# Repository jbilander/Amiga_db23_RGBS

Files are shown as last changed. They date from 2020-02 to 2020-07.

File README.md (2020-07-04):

# Amiga_DB23_RGBS
A small PCB with RGBS out from the Amiga d-sub db23 connector. Made with KiCad 5.1.2-1

### Updated v2 PCB

On request I made an updated PCB with the capacitor pads removed, 2 mm hole pitch giving two more GND holes. A little rerouting as well to provide for easier soldering when using cables with shielded wire pairs (signal + ground return). This PCB is not tested yet!

<a href="images/Amiga_db23_RGBS_v2_pic1.jpg">
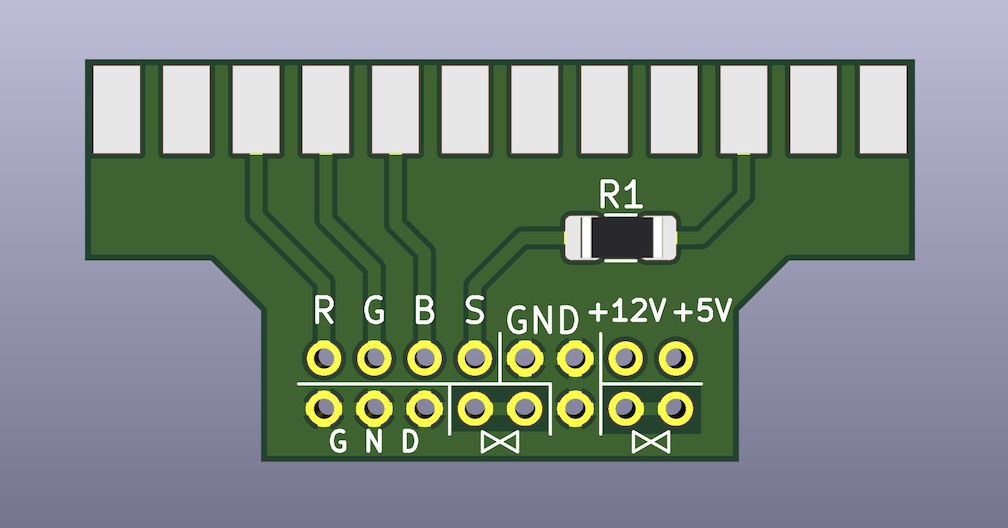
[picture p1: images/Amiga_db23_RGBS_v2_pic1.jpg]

</a>
<a href="images/Amiga_db23_RGBS_v2_pic2.jpg">
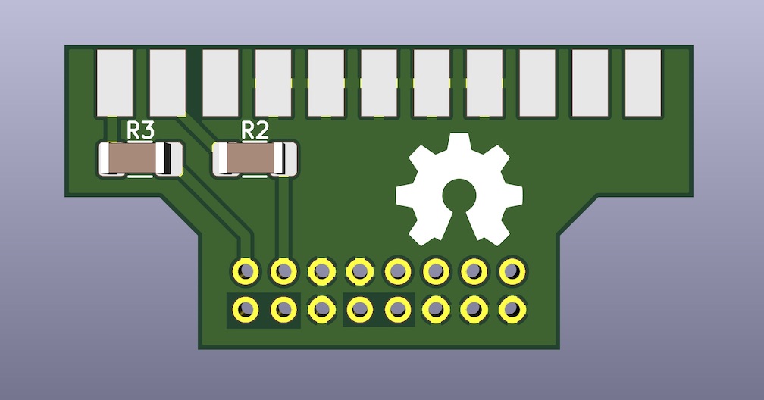
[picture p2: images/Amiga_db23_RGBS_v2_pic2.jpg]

</a>
<a href="images/Amiga_db23_RGBS_v2_pic3.jpg">
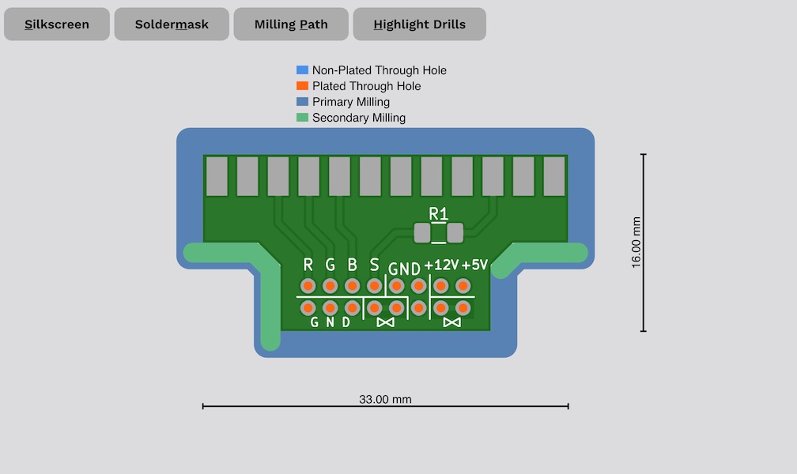
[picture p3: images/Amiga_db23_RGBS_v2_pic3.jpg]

</a>
<a href="images/Amiga_db23_RGBS_v2_pic4.jpg">
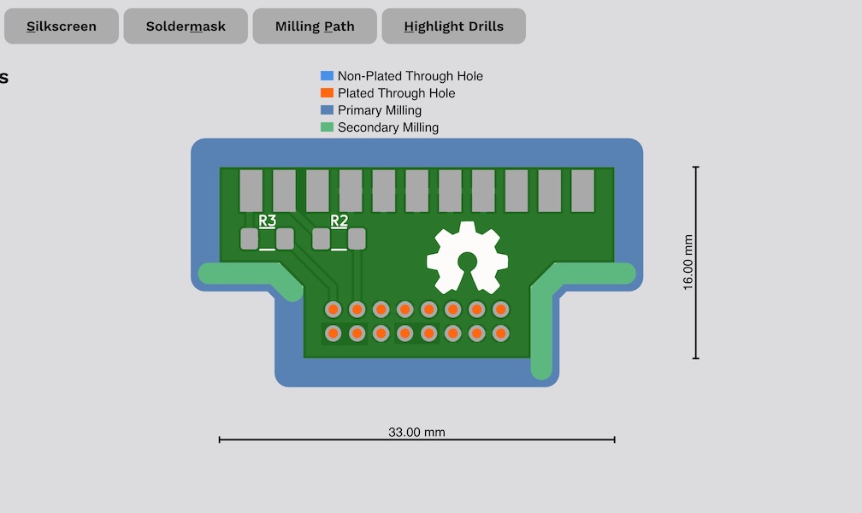
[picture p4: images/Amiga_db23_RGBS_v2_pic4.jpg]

</a>
<a href="images/Amiga_db23_RGBS_v2_pic5.jpg">
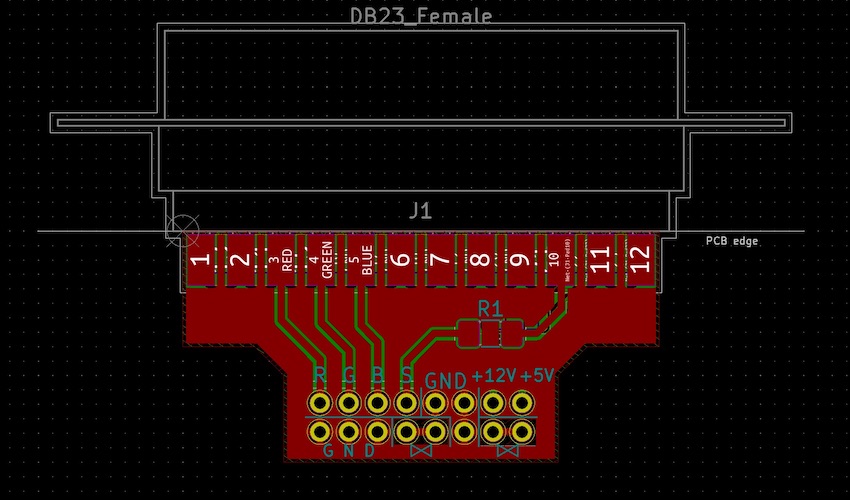
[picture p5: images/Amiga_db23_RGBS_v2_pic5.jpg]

</a>

***

Update: On some cables I got a lot of noise/interference in the signal and needed to connect the shielding on the plugs on each end `d-sub metal shield <-> SCART metal shield` to get rid of it.

***

<a href="images/Amiga_db23_RGBS_pic1.jpg">
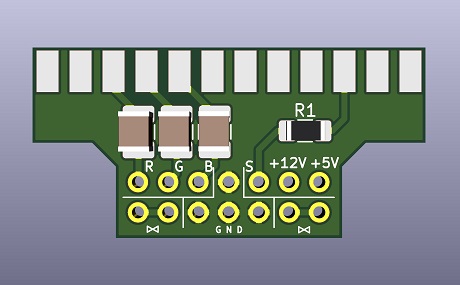
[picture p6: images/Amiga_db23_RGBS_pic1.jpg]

</a>
<a href="images/Amiga_db23_RGBS_pic2.jpg">
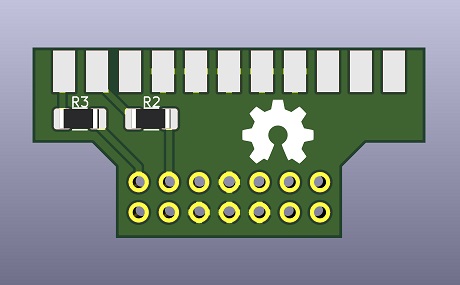
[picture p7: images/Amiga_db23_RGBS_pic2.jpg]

</a>
<a href="images/Amiga_db23_RGBS_pic3.jpg">
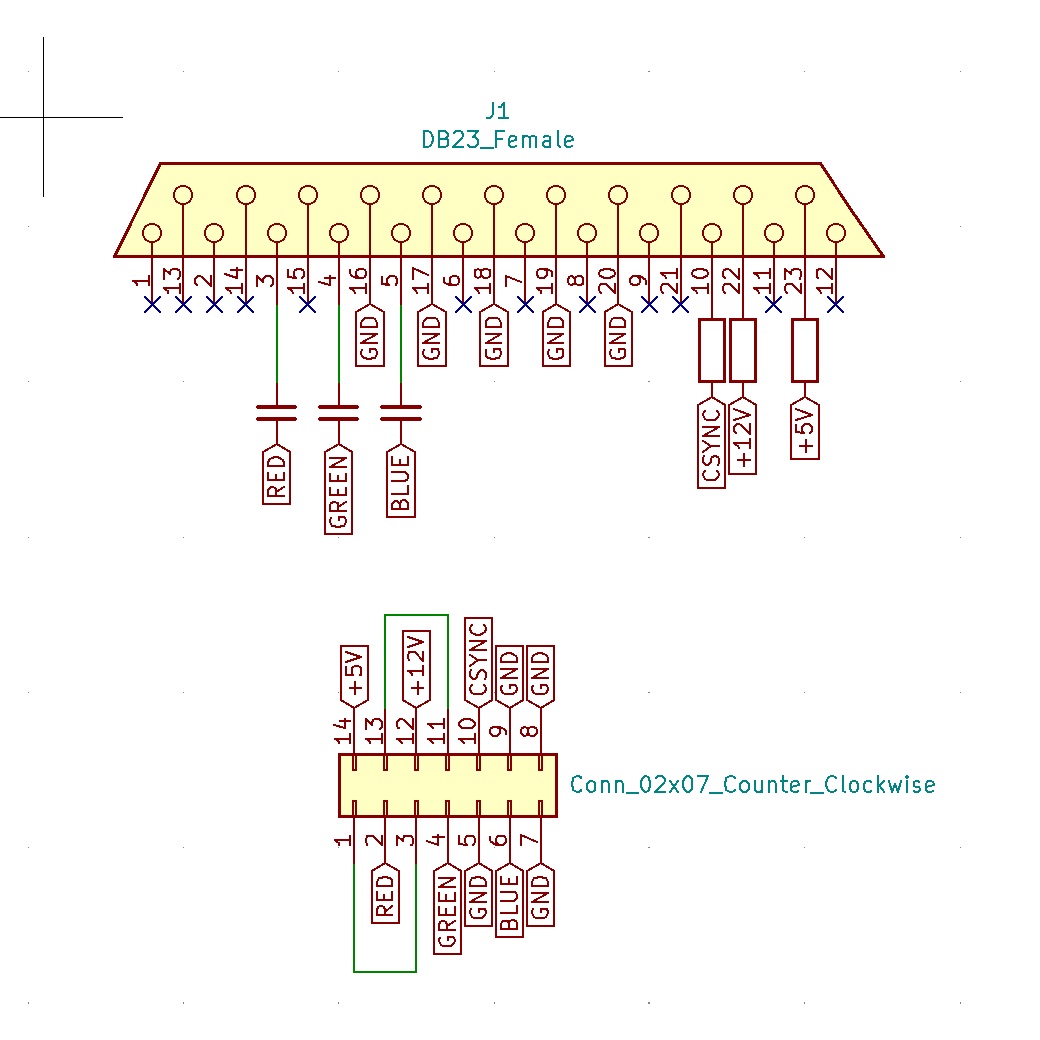
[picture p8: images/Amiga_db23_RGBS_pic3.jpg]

</a>
<a href="images/Amiga_db23_RGBS_pic4.jpg">
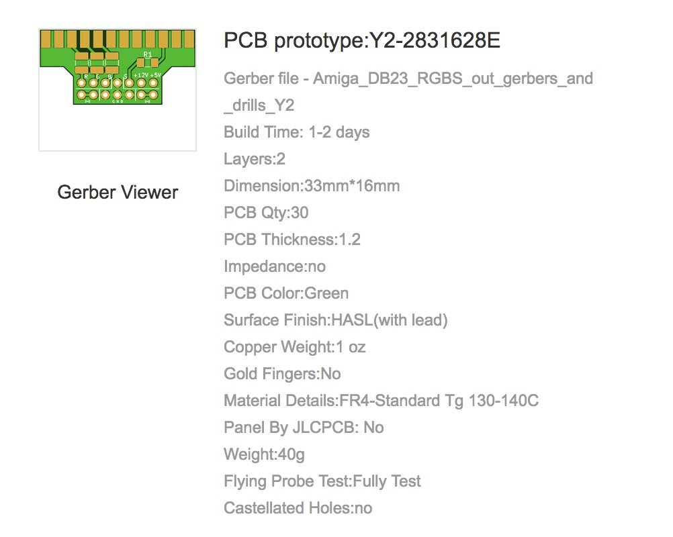
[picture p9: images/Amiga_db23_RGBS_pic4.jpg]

</a>

***

<a href="images/Amiga_db23_RGBS_pic5.jpg">
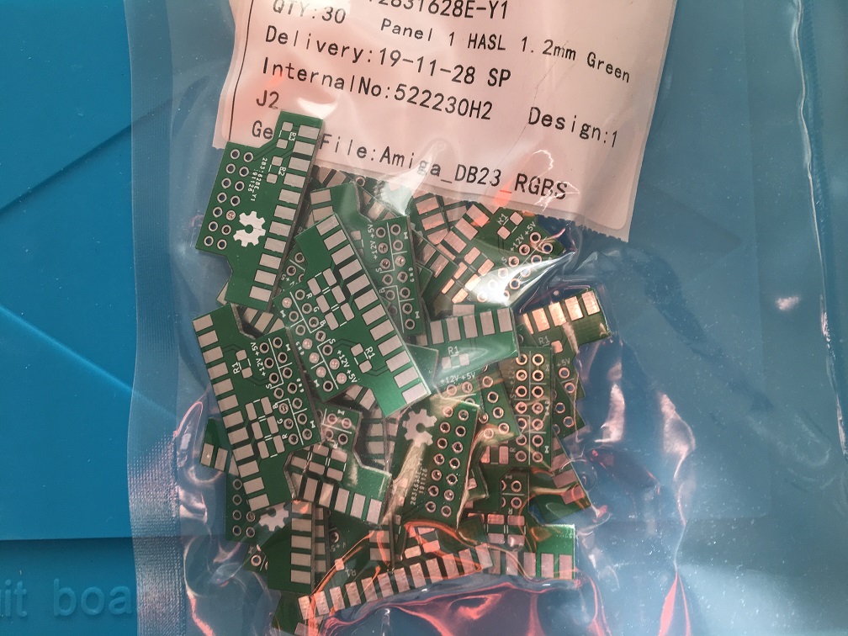
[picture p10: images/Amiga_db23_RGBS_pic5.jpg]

</a>
<a href="images/Amiga_db23_RGBS_pic6.jpg">
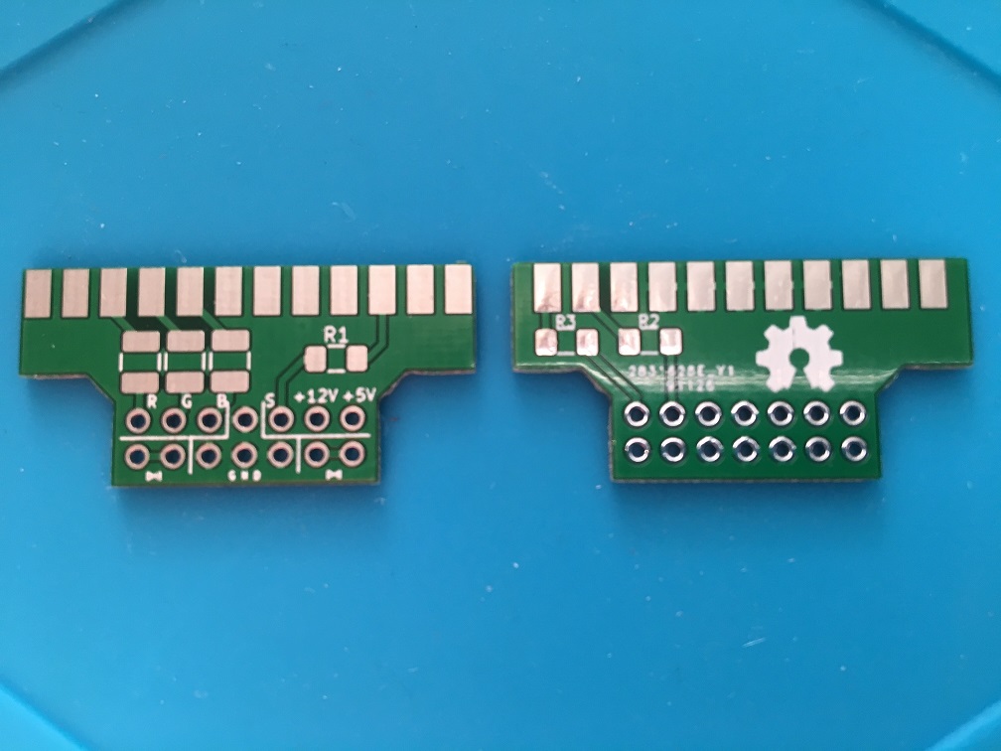
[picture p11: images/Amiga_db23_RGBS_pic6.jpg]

</a>
<a href="images/Amiga_db23_RGBS_pic7.jpg">
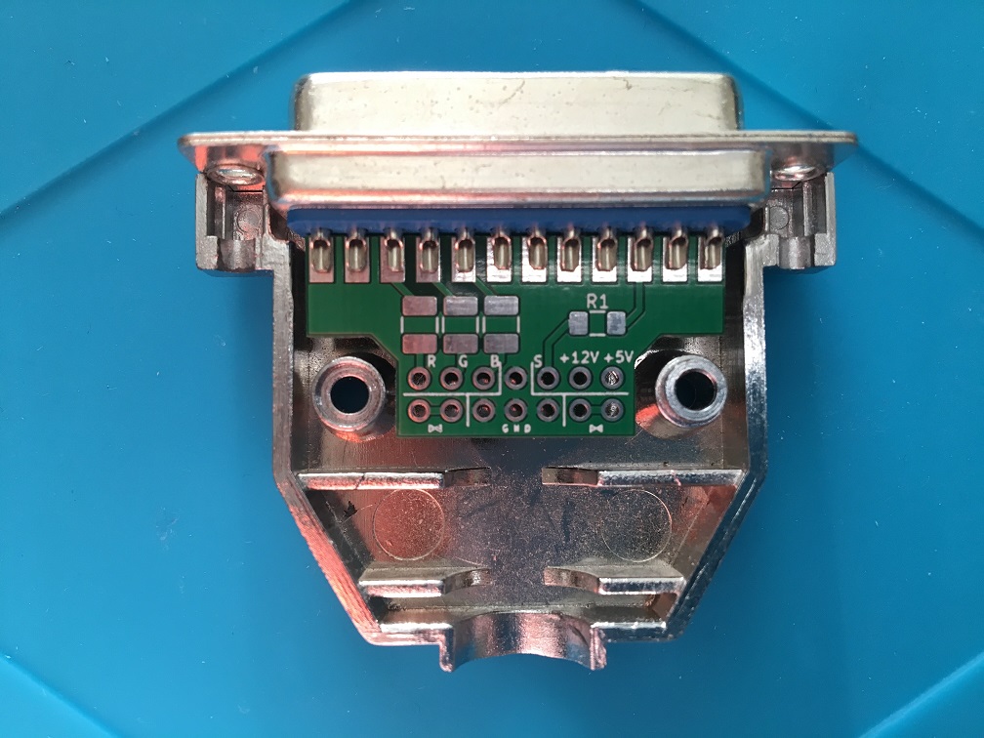
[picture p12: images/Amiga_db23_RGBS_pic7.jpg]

</a>

***

Let's solder this one. I used `220uF 16V size 1210` as coupling capacitors for the RGB pads. All resistors `size 1206`, I used the following values `R1: 330 Ohm, R2: 1K Ohm, R3: 75 Ohm`, following Stedy's guide here: The Ultimate SCART cable v1.1 http://www.ianstedman.co.uk/Amiga/amiga_hacks/Amiga_SCART/amiga_scart.html Not using pin 13 though as ground return but rather following this picture: https://ilesj.files.wordpress.com/2012/01/amiga_rgb-scart-diagram.png

<a href="images/Amiga_db23_RGBS_pic9.jpg">
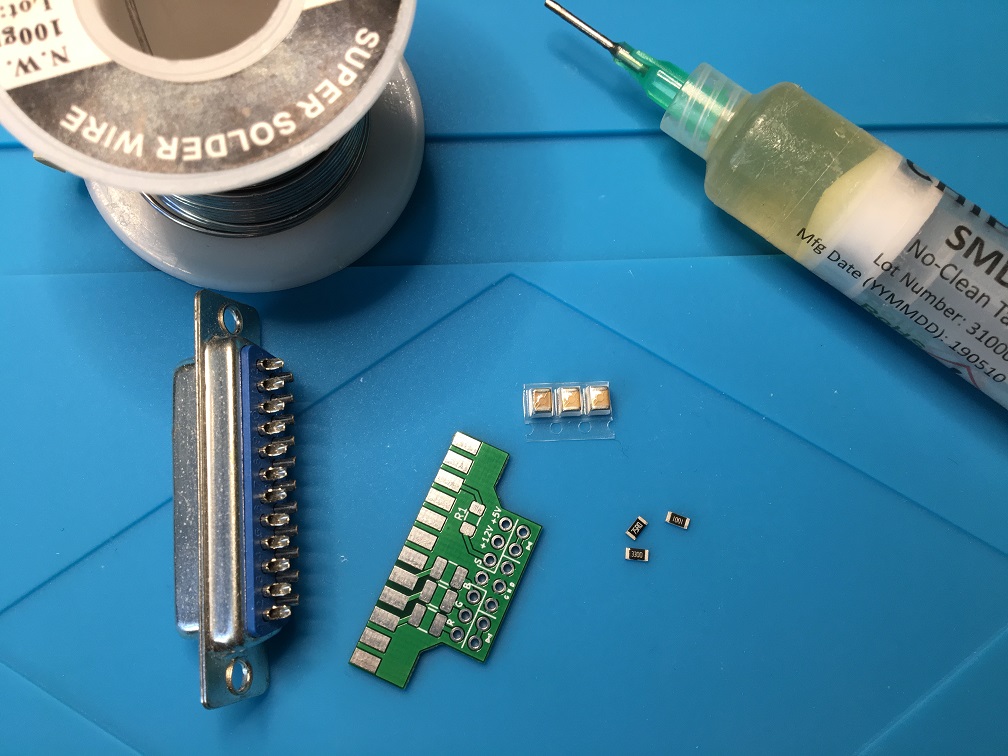
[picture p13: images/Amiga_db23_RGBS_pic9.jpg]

</a>
<a href="images/Amiga_db23_RGBS_pic10.jpg">
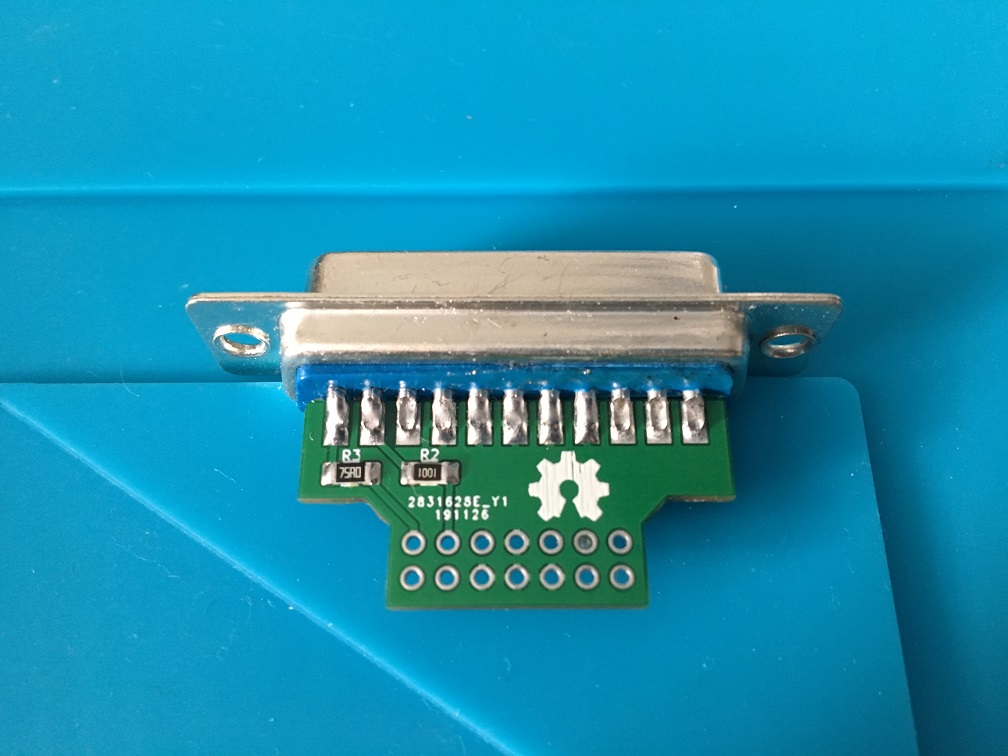
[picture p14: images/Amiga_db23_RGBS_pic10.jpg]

</a>
<a href="images/Amiga_db23_RGBS_pic11.jpg">
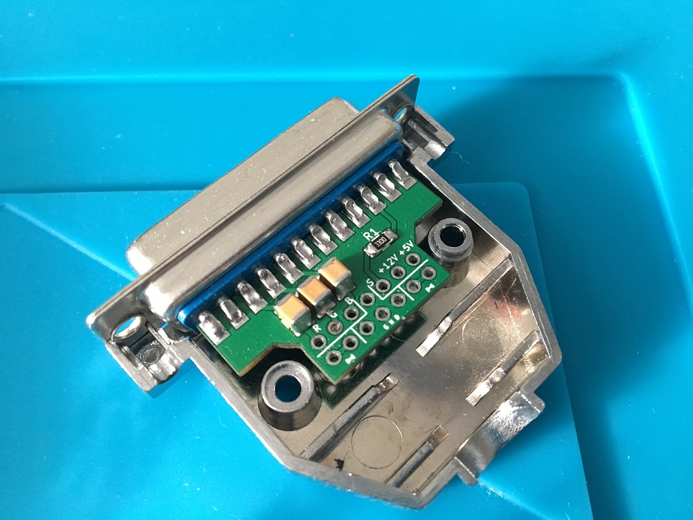
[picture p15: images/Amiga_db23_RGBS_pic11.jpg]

</a>

***
I used an old DVI<->Vga cable that I butchered cutting off the plugs on both ends. I also found an old composite rca cable yellow-red-white laying around. I used the red-white part for the Audio. When making a cable with a SCART plug it makes sense to run the Left/Right audio wires inside the cable since the connector has both RGB video and stereo audio pins as standard. You can run the audio wires separately should you want to.

<a href="images/Amiga_db23_RGBS_pic12.jpg">
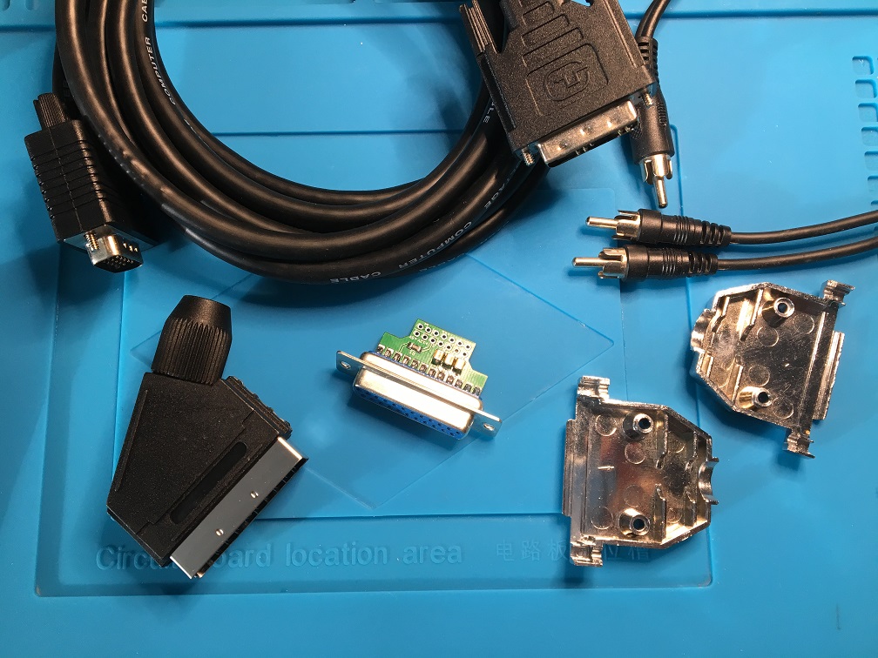
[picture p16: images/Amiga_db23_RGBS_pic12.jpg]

</a>
<a href="images/Amiga_db23_RGBS_pic13.jpg">
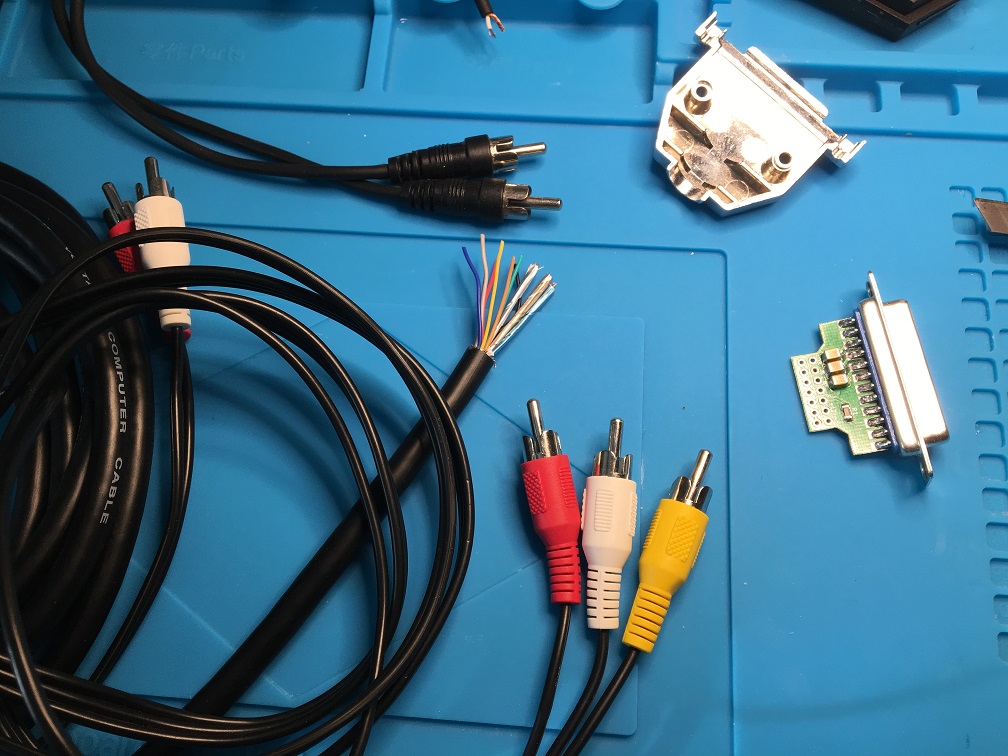
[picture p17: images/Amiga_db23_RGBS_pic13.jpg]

</a>
<br /><br />
I started with soldering the audio wires to the extension sides, holes with the "interconnected" symbol.
<br />
<a href="images/Amiga_db23_RGBS_pic14.jpg">
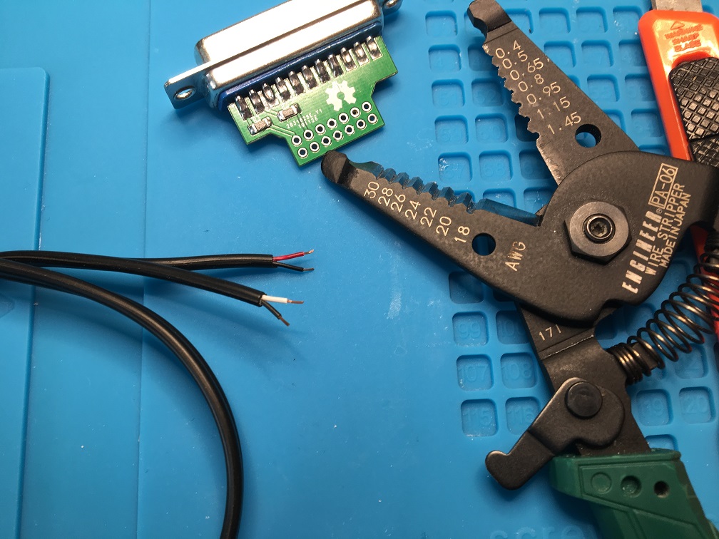
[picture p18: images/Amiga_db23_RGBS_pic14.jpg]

</a>
<a href="images/Amiga_db23_RGBS_pic15.jpg">
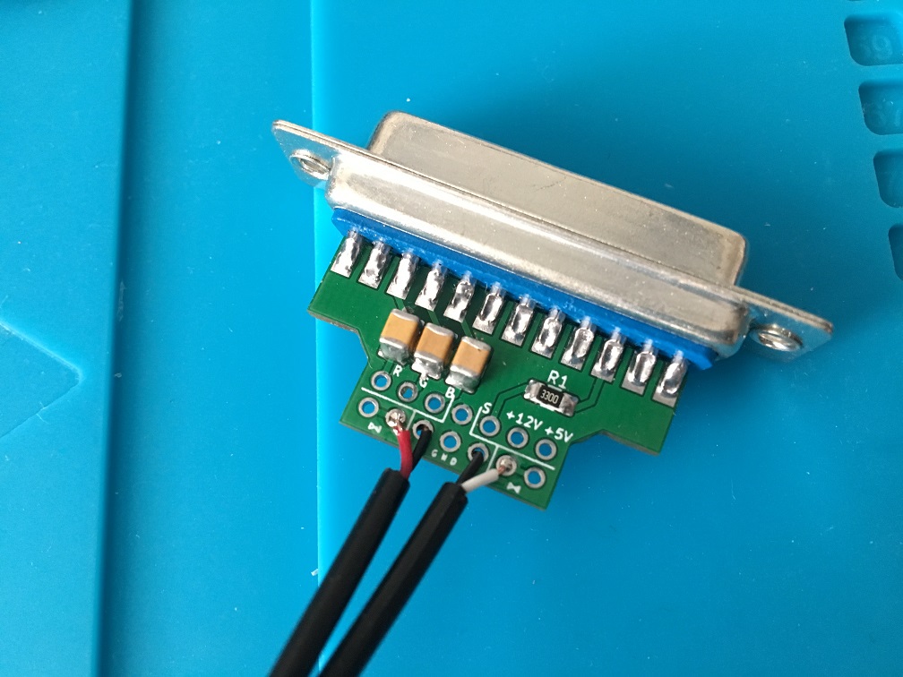
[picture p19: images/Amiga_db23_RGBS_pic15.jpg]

</a>
<a href="images/Amiga_db23_RGBS_pic16.jpg">
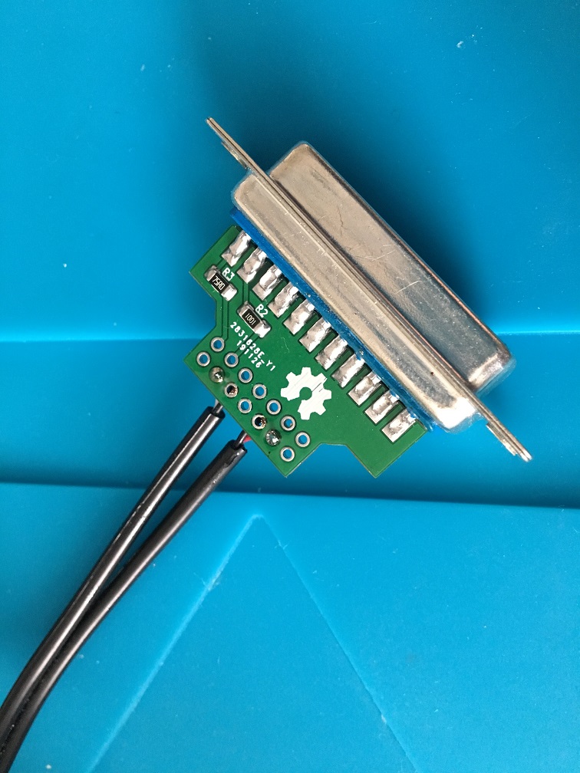
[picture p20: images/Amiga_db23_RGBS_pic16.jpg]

</a>

***

And then the rest, I used the three shielded wires for the RGB lines.

<a href="images/Amiga_db23_RGBS_pic17.jpg">
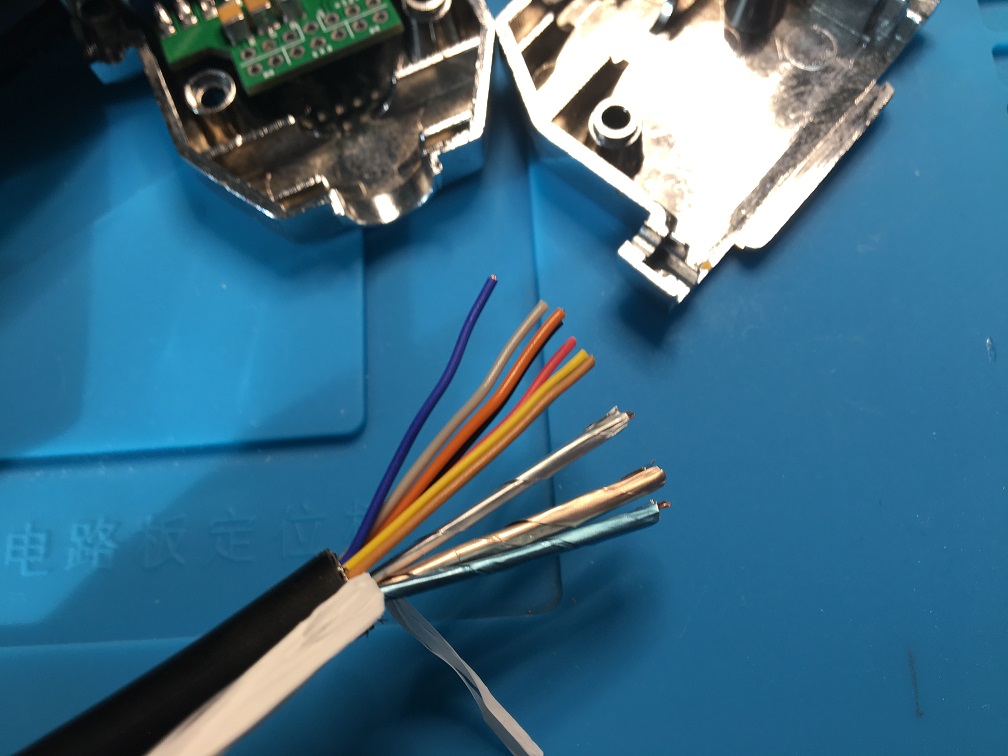
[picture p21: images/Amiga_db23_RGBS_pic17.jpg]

</a>
<a href="images/Amiga_db23_RGBS_pic18.jpg">
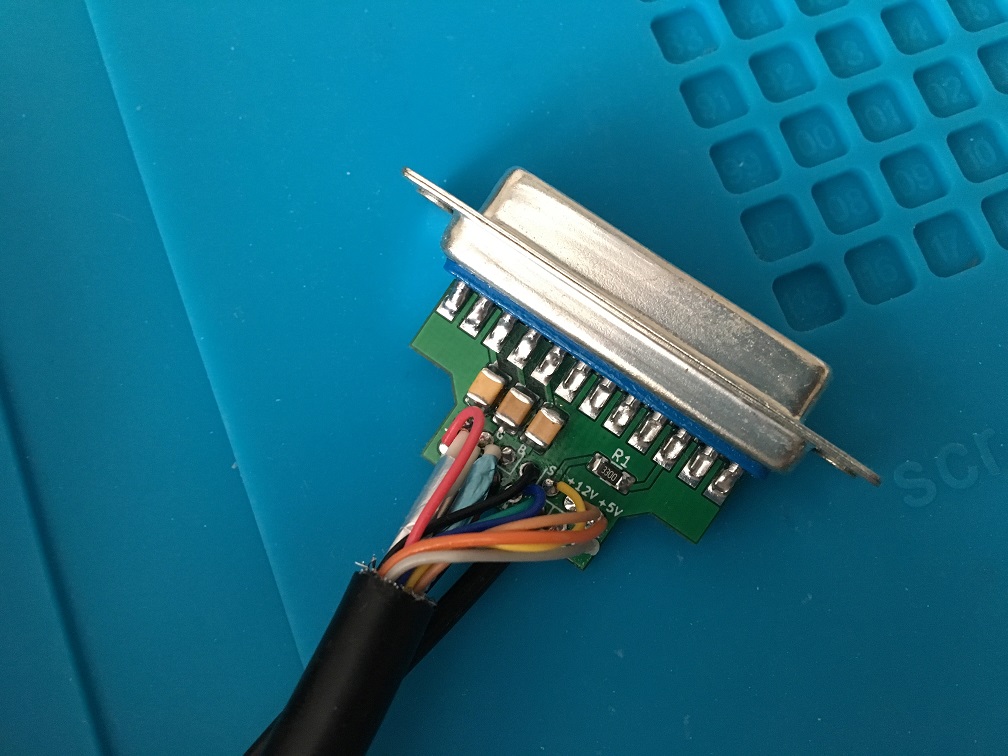
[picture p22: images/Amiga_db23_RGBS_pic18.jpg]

</a>
<a href="images/Amiga_db23_RGBS_pic19.jpg">
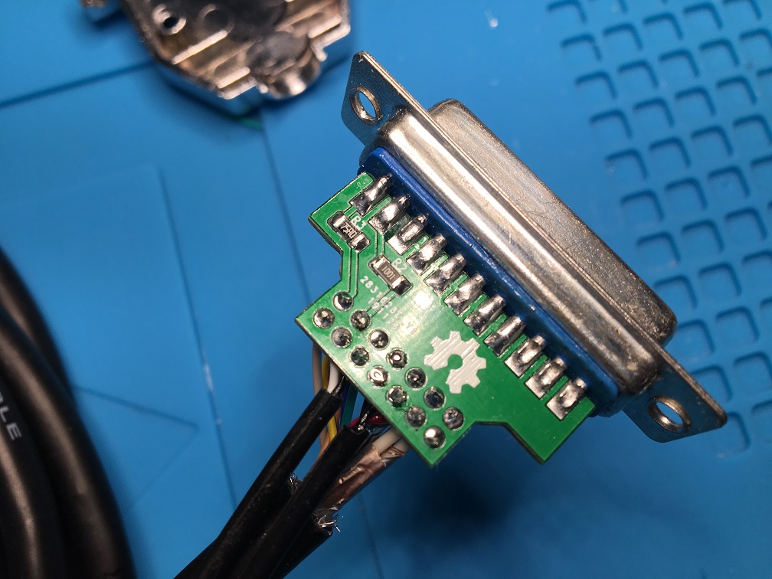
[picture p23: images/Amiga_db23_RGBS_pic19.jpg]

</a>
<a href="images/Amiga_db23_RGBS_pic20.jpg">
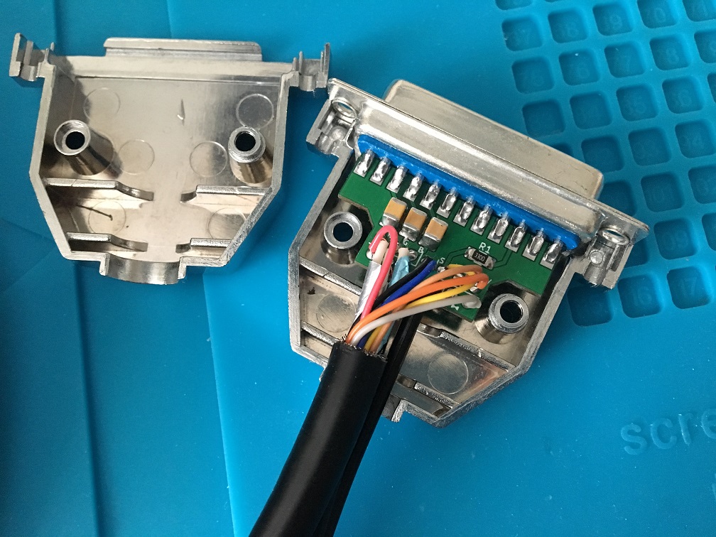
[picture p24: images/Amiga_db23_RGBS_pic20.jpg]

</a>
<a href="images/Amiga_db23_RGBS_pic21.jpg">
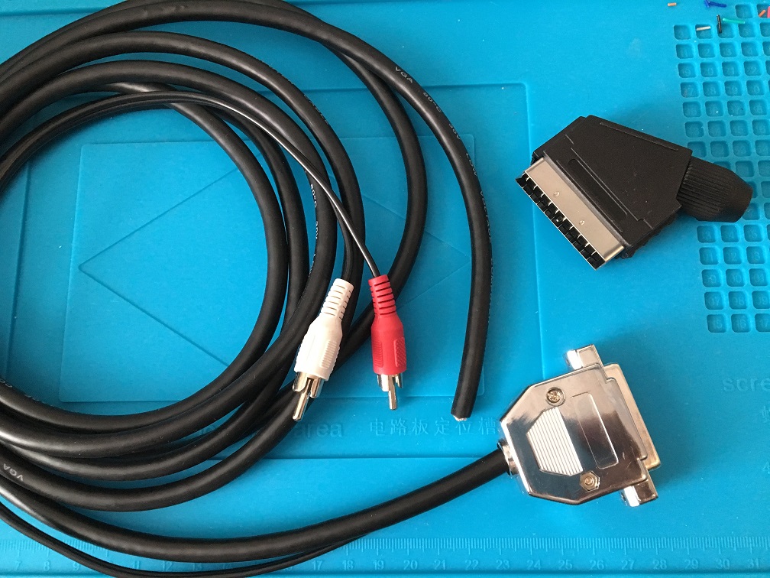
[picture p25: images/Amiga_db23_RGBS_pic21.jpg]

</a>
<a href="images/Amiga_db23_RGBS_pic22.jpg">
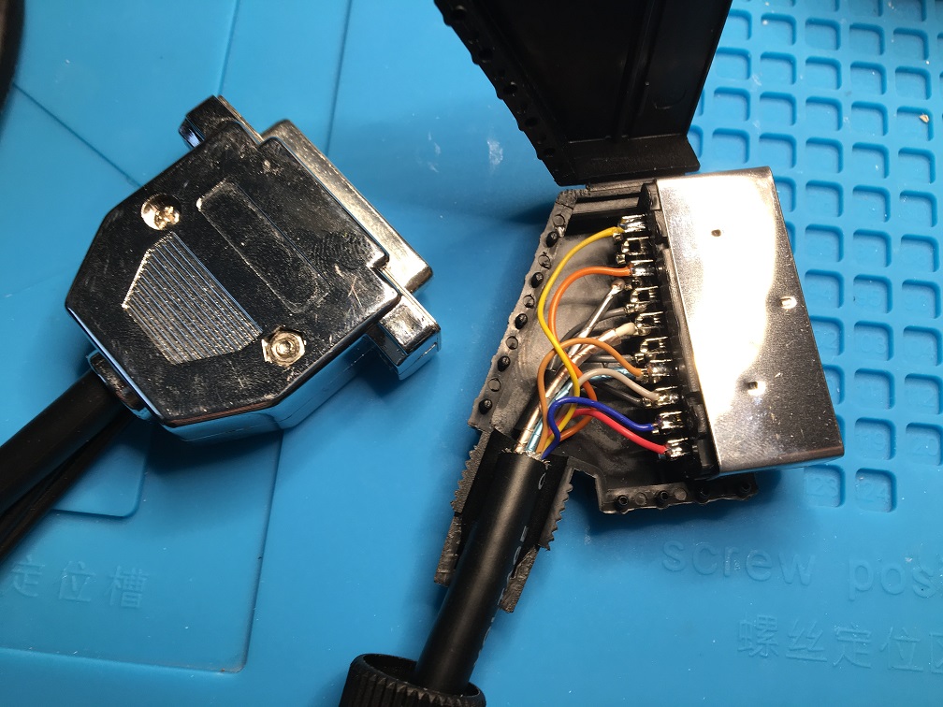
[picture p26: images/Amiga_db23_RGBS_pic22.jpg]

</a>
<a href="images/Amiga_db23_RGBS_pic23.jpg">
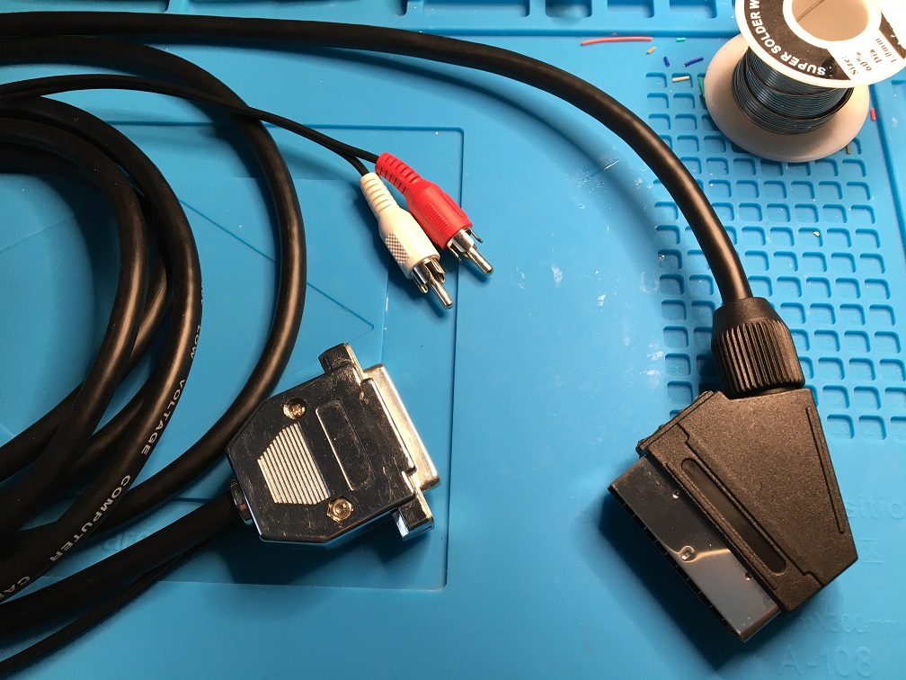
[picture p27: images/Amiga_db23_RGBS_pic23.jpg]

</a>

***

Moment of truth, hooking it up to the Amiga and yes it does work...I noticed I get more subtle vertical stripes with this cable then other Scart's I have tried, However I can still notice some "jailbars", check the last picture here from the game Another World. This is on my old Samsung LCD from 2005 that has seen better days. It is better on my plasma.

***

<a href="images/Amiga_db23_RGBS_pic24.jpg">
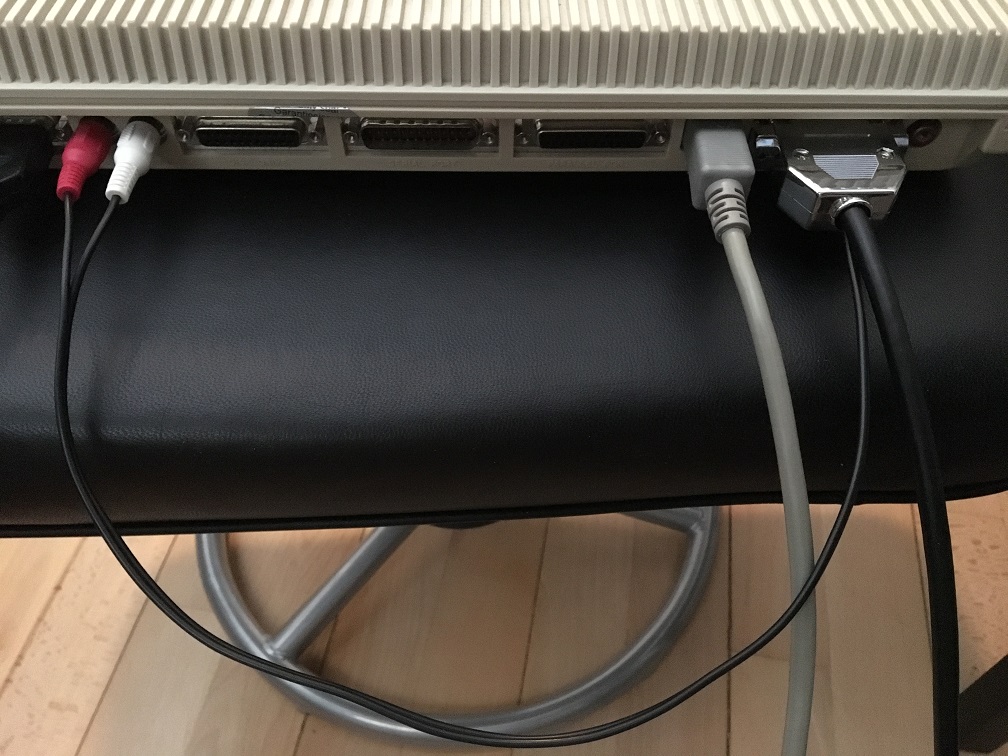
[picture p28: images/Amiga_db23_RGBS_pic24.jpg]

</a>
<a href="images/Amiga_db23_RGBS_pic25.jpg">
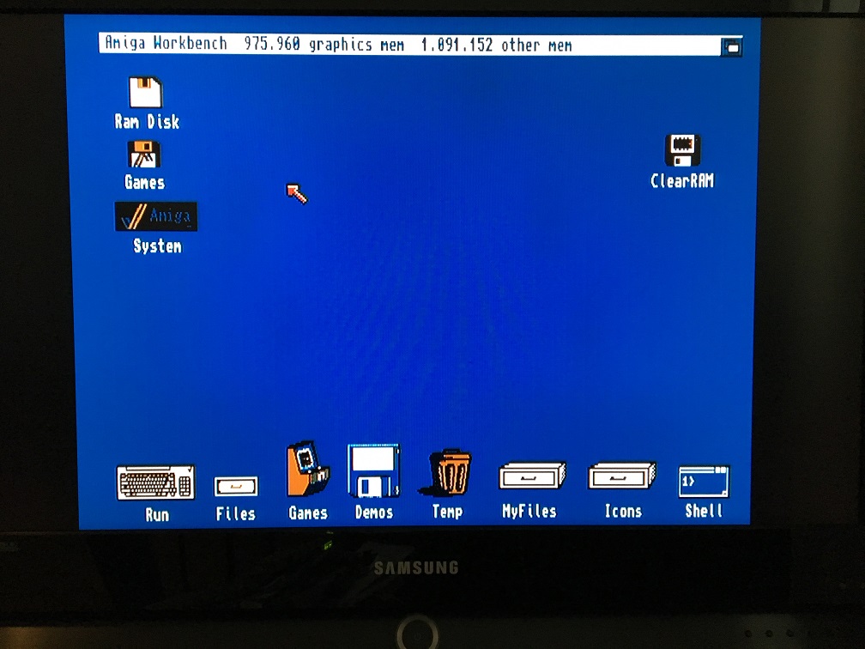
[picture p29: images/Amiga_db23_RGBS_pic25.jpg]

</a>
<a href="images/Amiga_db23_RGBS_pic26.jpg">
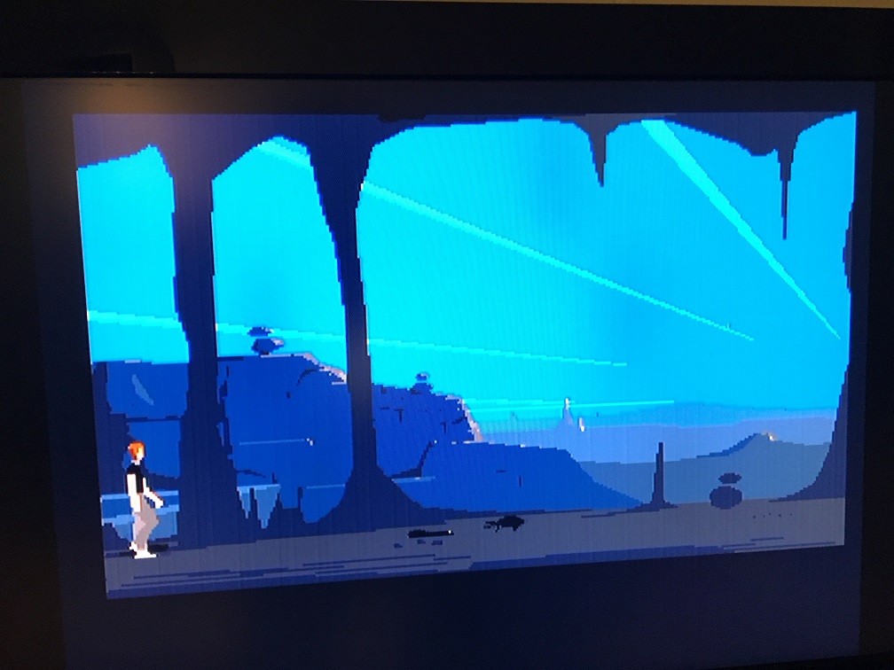
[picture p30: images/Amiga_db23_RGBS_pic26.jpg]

</a>
<a href="images/Amiga_db23_RGBS_pic27.jpg">
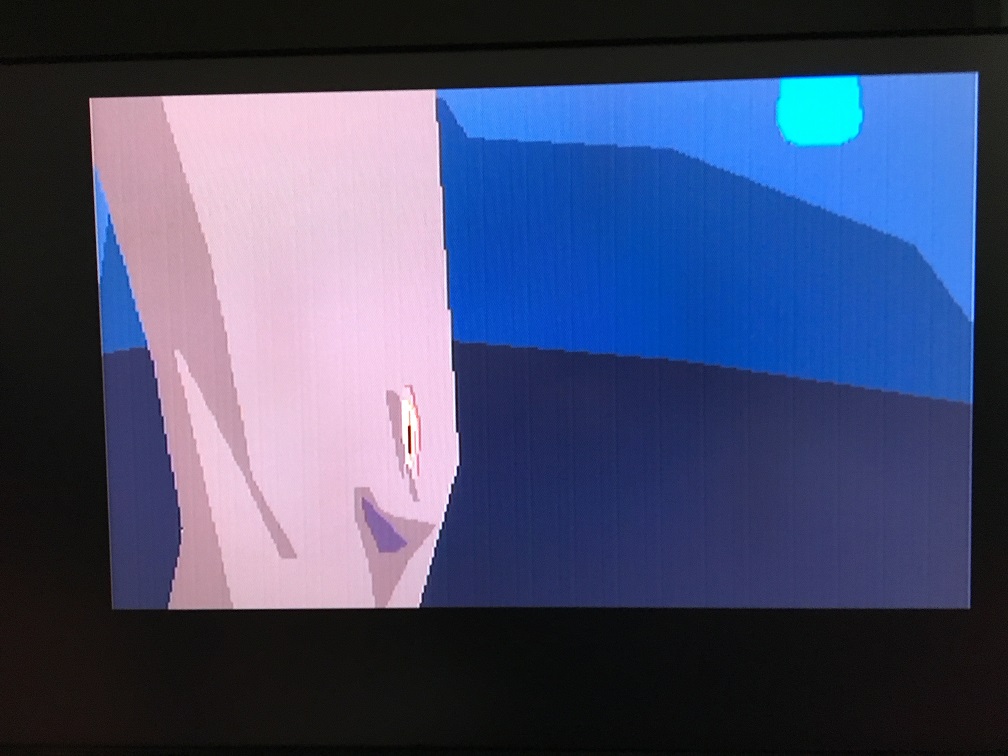
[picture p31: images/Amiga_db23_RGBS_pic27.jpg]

</a>

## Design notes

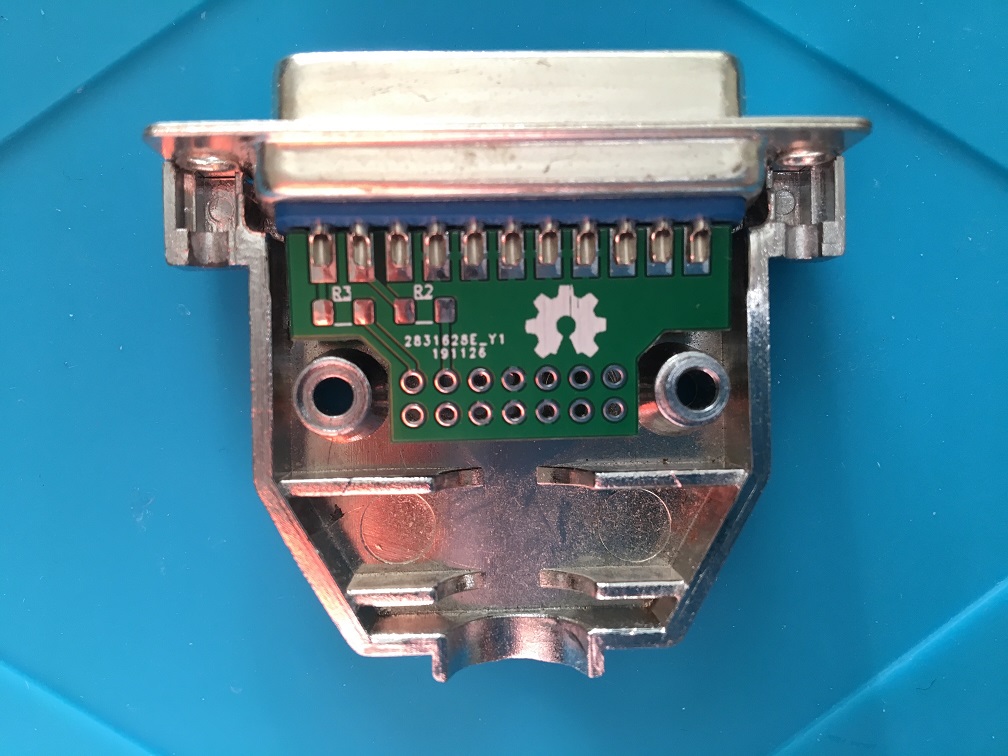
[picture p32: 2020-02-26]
images/Amiga_db23_RGBS_pic8.jpg

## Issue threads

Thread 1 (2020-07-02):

Amiga DB23 RGBS

danko79, 2020-07-02:
Hi, I don't know how to contact her, I need 3 DIY kits pcb with all caps and resistors of these are available?

jbilander, 2020-07-02:
Hi,

Send me an email with your postal address and I can send you 3 pcs pcb + components and you can try it out. My email:

jorgen.bilander at gmail com

I recently made a cable with just using zero ohm resistors on the RGB lines, it worked well but I had to connect the shielding on the plugs as well to get rid of noise. Maybe the cable I used wasn't the best.

Regards, /JB

Closed 2020-07-03.

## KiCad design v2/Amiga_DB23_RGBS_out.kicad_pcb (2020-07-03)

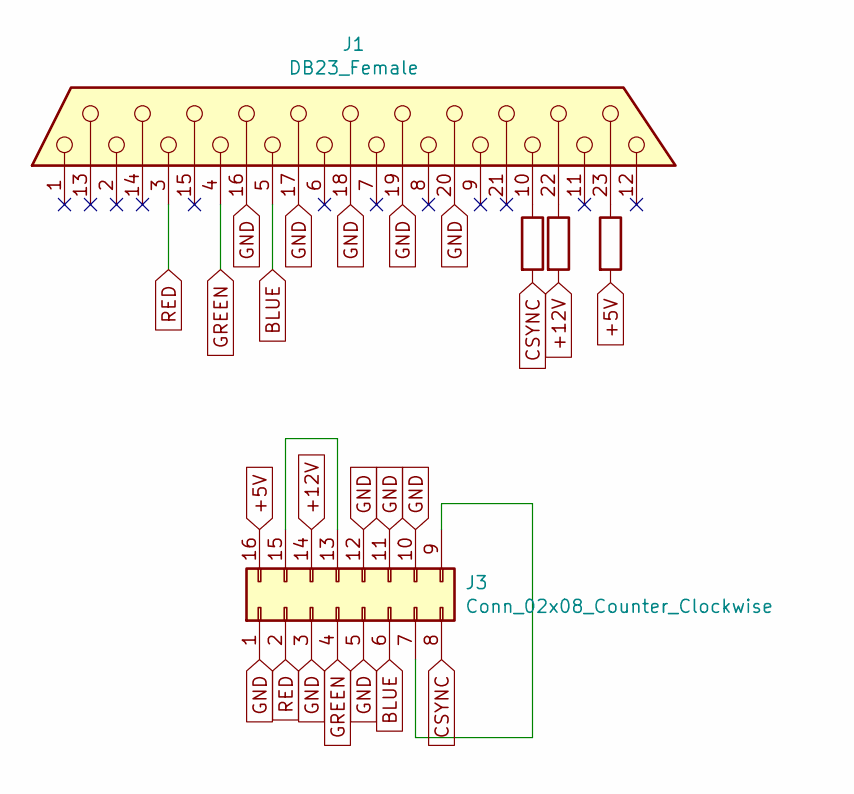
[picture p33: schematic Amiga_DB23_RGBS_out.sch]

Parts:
J1: DB23_Female; DSUB-23_Female_EdgeMount_P2.77mm
J3: Conn_02x08_Counter_Clockwise; PinHeader_2x08_P2.00mm_Vertical
R1: R330; R_1206_3216Metric_Pad1.42x1.75mm_HandSolder
R2: R; C_1206_3216Metric_Pad1.42x1.75mm_HandSolder
R3: R110; C_1206_3216Metric_Pad1.42x1.75mm_HandSolder

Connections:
+5V: J3.16, R3.2
+12V: J3.14, R2.2
BLUE: J1.5, J3.6
CSYNC: J3.8, R1.2
GND: J1.16, J1.17, J1.18, J1.19, J1.20, J3.1, J3.3, J3.5, J3.10, J3.11, J3.12
GREEN: J1.4, J3.4
unnamed: J1.10, R1.1
unnamed: J1.22, R2.1
unnamed: J1.23, R3.1
unnamed: J3.7, J3.9
unnamed: J3.13, J3.15
RED: J1.3, J3.2

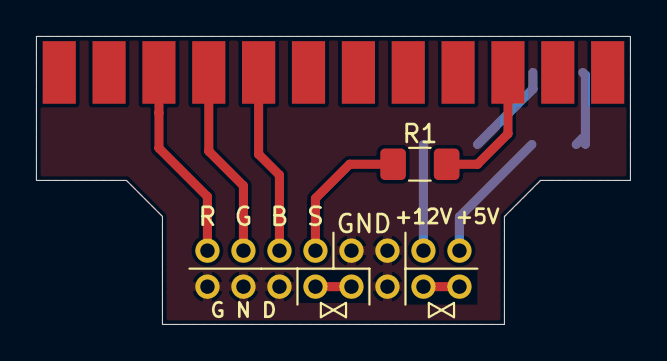
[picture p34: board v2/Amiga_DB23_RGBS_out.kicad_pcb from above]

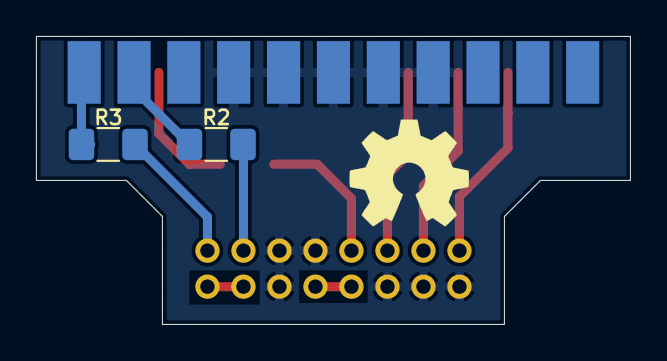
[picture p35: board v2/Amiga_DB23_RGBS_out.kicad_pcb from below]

Board: 2 copper layers, 33.0 x 16.0 mm, 5 parts (2 on the bottom side), 12 nets.

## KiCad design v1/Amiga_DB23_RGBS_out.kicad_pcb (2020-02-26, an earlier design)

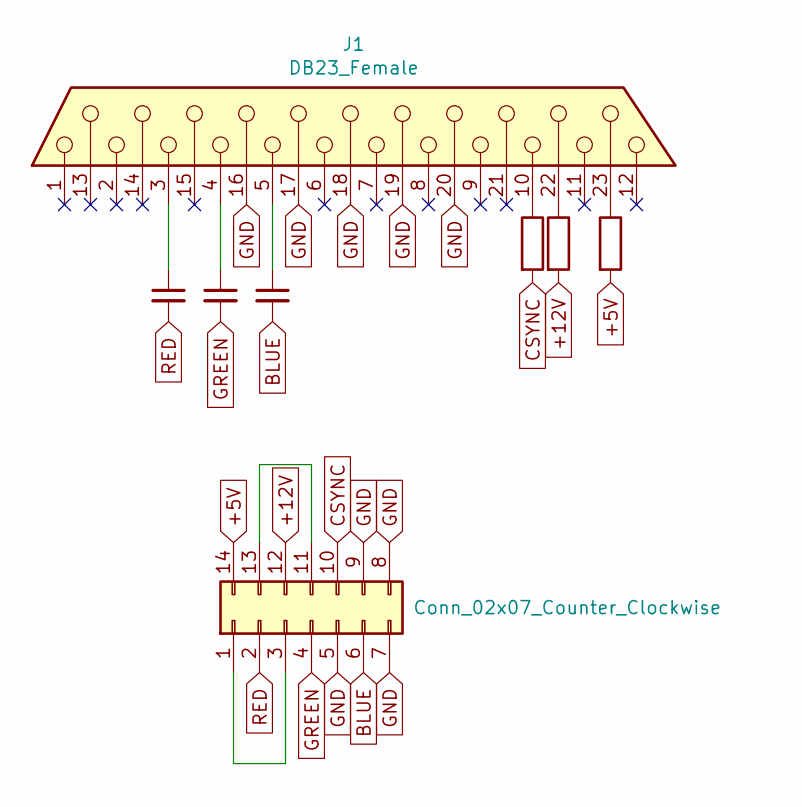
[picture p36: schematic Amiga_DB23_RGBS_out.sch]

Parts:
C1, C2, C3: C_Small; C_1210_3225Metric_Pad1.42x2.65mm_HandSolder
J1: DB23_Female; DSUB-23_Female_EdgeMount_P2.77mm
J2: Conn_02x07_Counter_Clockwise; PinHeader_2x07_P2.54mm_Vertical
R1: R330; R_1206_3216Metric_Pad1.42x1.75mm_HandSolder
R2: R; C_1206_3216Metric_Pad1.42x1.75mm_HandSolder
R3: R110; C_1206_3216Metric_Pad1.42x1.75mm_HandSolder

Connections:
+5V: J2.14, R3.2
+12V: J2.12, R2.2
BLUE: C3.2, J2.6
CSYNC: J2.10, R1.2
GND: J1.16, J1.17, J1.18, J1.19, J1.20, J2.5, J2.7, J2.8, J2.9
GREEN: C2.2, J2.4
unnamed: C1.1, J1.3
unnamed: C2.1, J1.4
unnamed: C3.1, J1.5
unnamed: J1.10, R1.1
unnamed: J1.22, R2.1
unnamed: J1.23, R3.1
unnamed: J2.1, J2.3
unnamed: J2.11, J2.13
RED: C1.2, J2.2

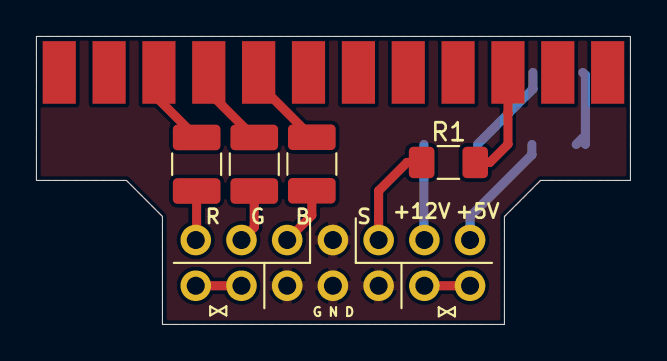
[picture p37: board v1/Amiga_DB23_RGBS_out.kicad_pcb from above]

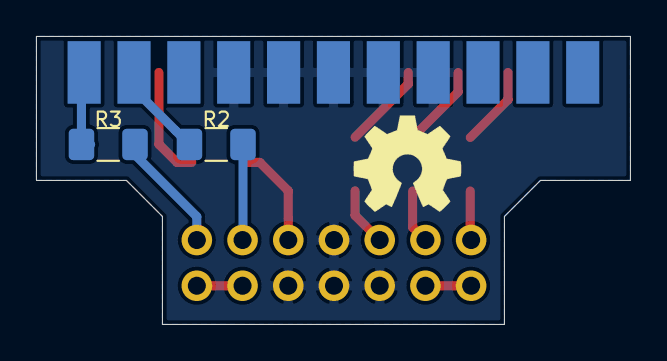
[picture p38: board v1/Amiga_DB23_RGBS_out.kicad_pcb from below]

Board: 2 copper layers, 33.0 x 16.0 mm, 8 parts (2 on the bottom side), 15 nets.

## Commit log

2020-02-26 Added source files
    [Amiga_DB23_RGBS_out-B_Cu.gbr, Amiga_DB23_RGBS_out-B_Mask.gbr, Amiga_DB23_RGBS_out-B_Paste.gbr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]
2020-07-03 added new version
    [Amiga_DB23_RGBS_out-B_Cu.gbr, Amiga_DB23_RGBS_out-B_Mask.gbr, Amiga_DB23_RGBS_out-B_Paste.gbr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]
